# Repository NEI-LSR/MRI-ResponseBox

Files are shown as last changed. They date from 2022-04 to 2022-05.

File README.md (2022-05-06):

# MRI-ResponseBox
 Fiber optic manual response system for MRI use
 
 Contains:
  - **Code** contains the code loaded on the [Arduino](https://www.arduino.cc/en/Guide/Environment)
  - **FreeCad** contains the 3D model of the box using [FreeCad](https://www.freecadweb.org/)
  - **Eagle** contains the schematic of the electronics (see software [here](https://www.autodesk.com/products/eagle/features))

Note that the box should be put outside the scanner room (only the optic fiber should enter the room).

frontView
topView
backView

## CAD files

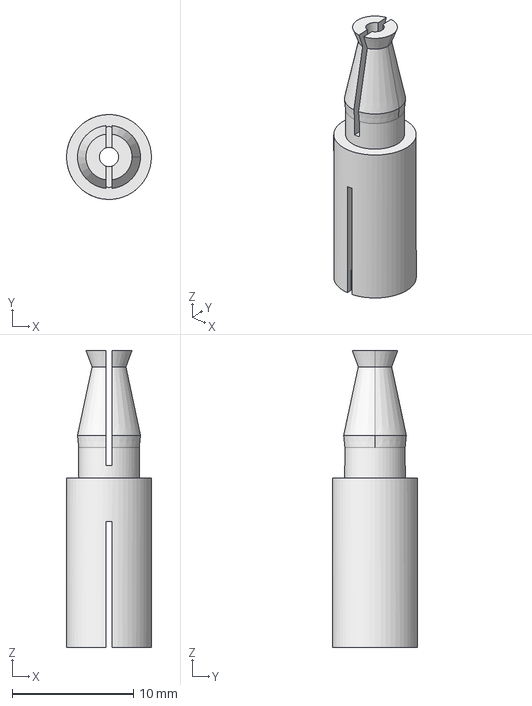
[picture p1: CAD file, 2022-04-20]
FreeCad/ResponseBoxLED-FiberConnector.FCStd
7.00 x 7.00 x 24.5 mm

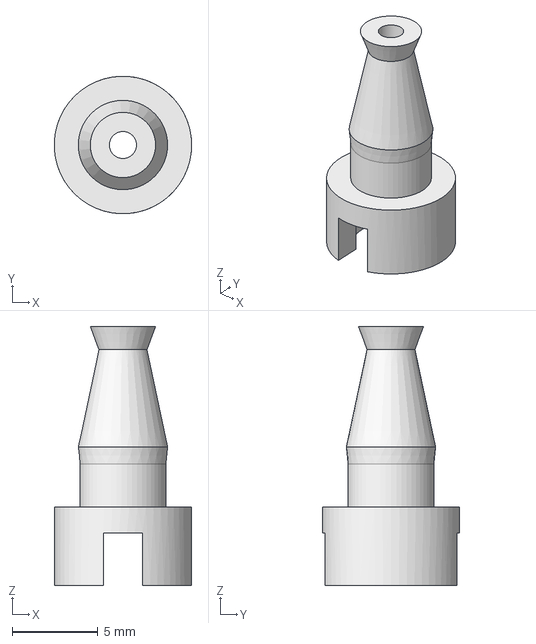
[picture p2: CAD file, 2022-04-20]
FreeCad/PhotoDiode_lgr.FCStd
7.99 x 8.00 x 15.1 mm

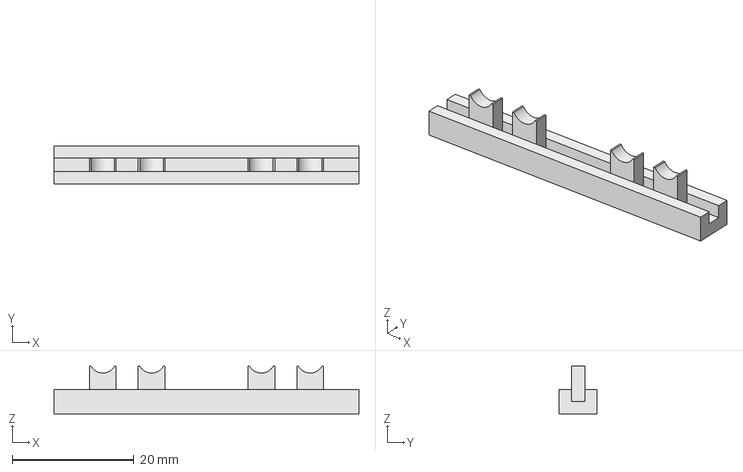
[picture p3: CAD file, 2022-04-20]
FreeCad/ResponseBox_testPlateTOP2b.FCStd
50.0 x 6.20 x 7.85 mm

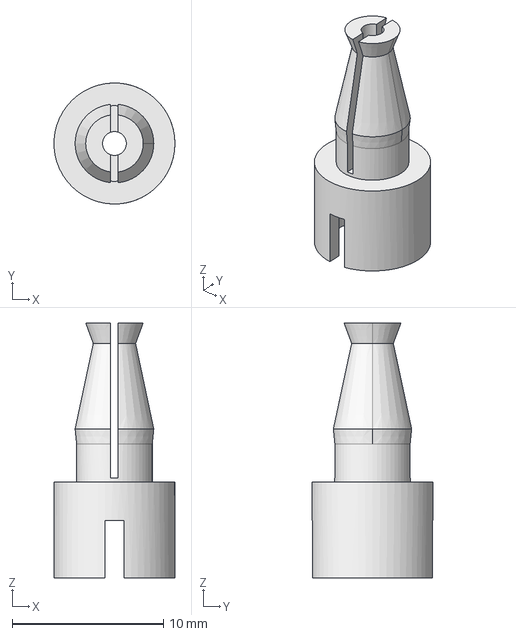
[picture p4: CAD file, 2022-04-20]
FreeCad/LaserDiode_a.FCStd
7.99 x 8.00 x 16.9 mm

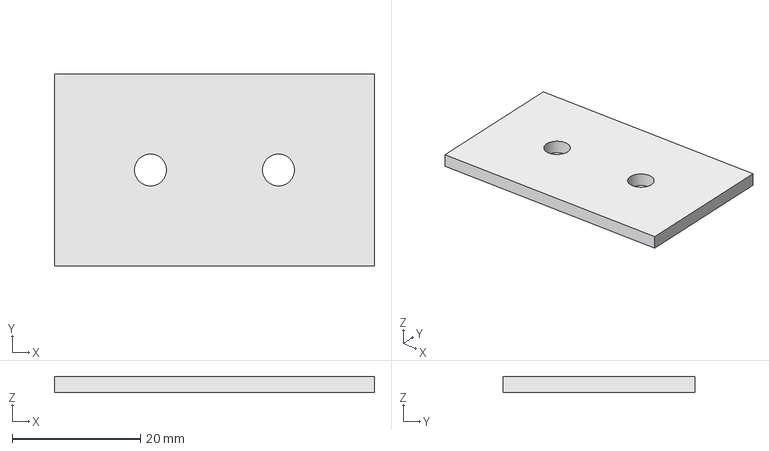
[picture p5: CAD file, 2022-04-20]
FreeCad/FiberHoldertestPlate2.FCStd
50.0 x 30.0 x 2.50 mm

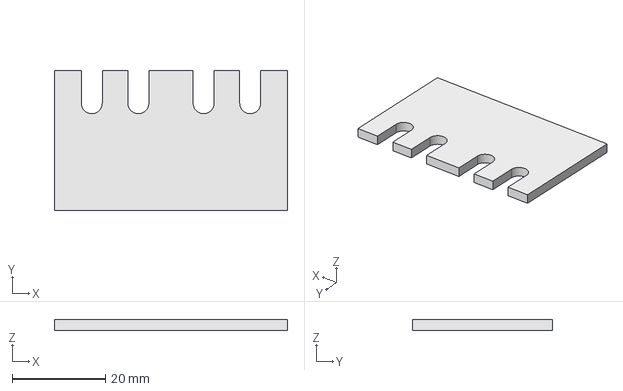
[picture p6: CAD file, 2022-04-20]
FreeCad/ResponseBox_testPlate2.FCStd
50.0 x 30.0 x 2.30 mm

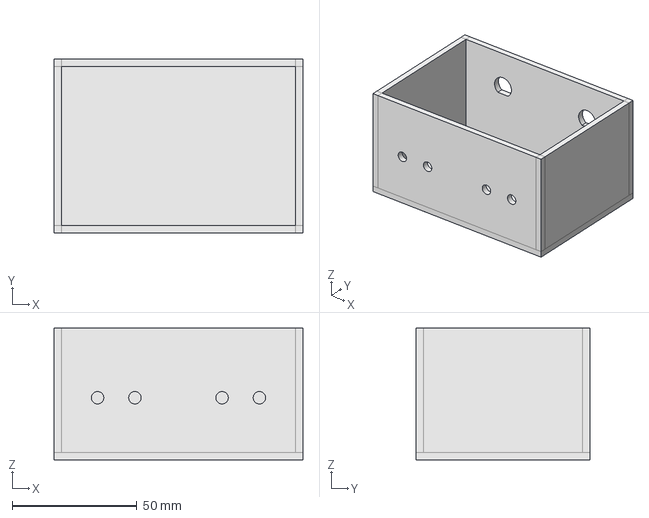
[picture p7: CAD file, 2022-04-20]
FreeCad/ResponseBox_a.FCStd
100.0 x 70.0 x 53.0 mm

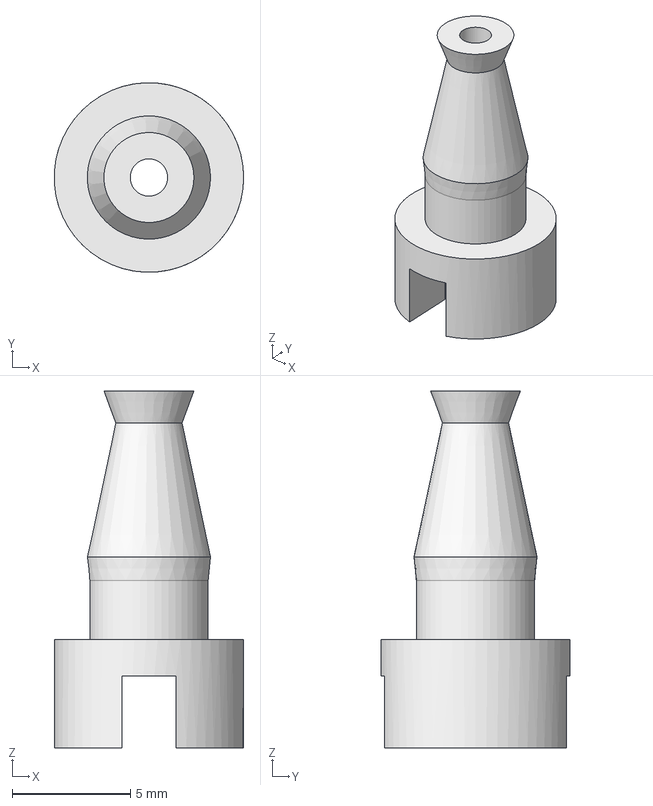
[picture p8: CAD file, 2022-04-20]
FreeCad/PhotoDiode_sm.FCStd
7.99 x 8.00 x 15.1 mm

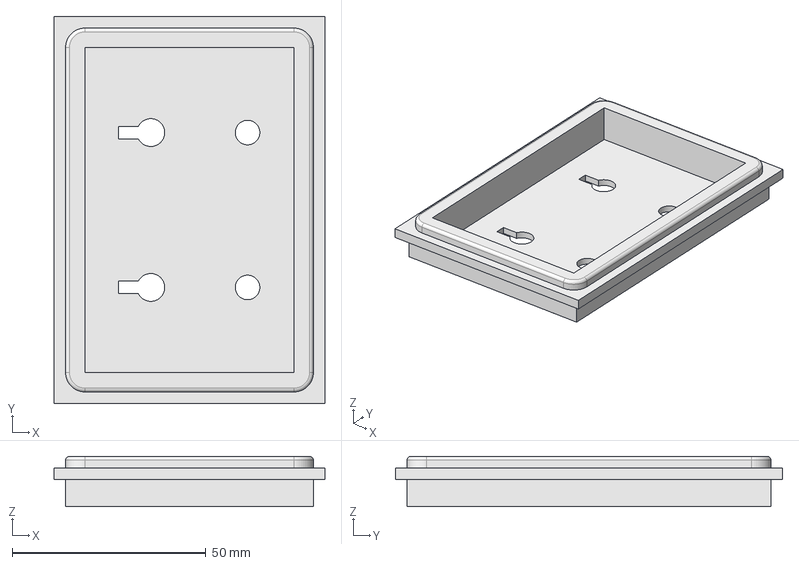
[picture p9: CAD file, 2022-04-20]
FreeCad/LickBoxTopProto2Chan.FCStd
70.0 x 100.0 x 13.0 mm

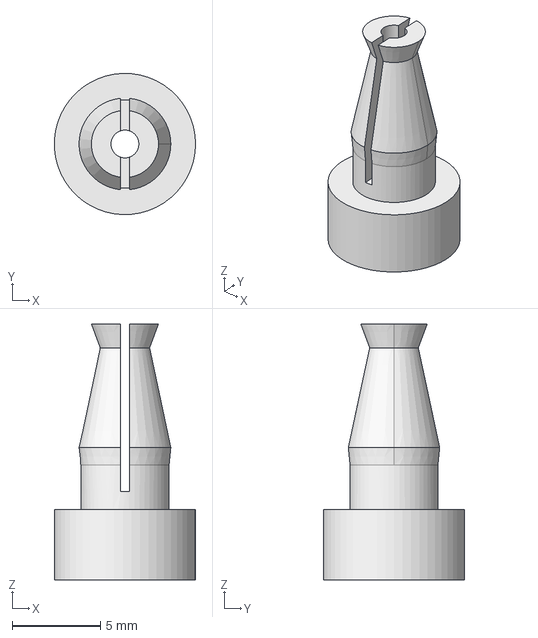
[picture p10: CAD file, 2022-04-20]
FreeCad/ResponseBoxPhotoDiode-FiberConnector.FCStd
7.99 x 8.00 x 14.5 mm

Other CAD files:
FreeCad/ResponseBox_testPlate2b.FCStd

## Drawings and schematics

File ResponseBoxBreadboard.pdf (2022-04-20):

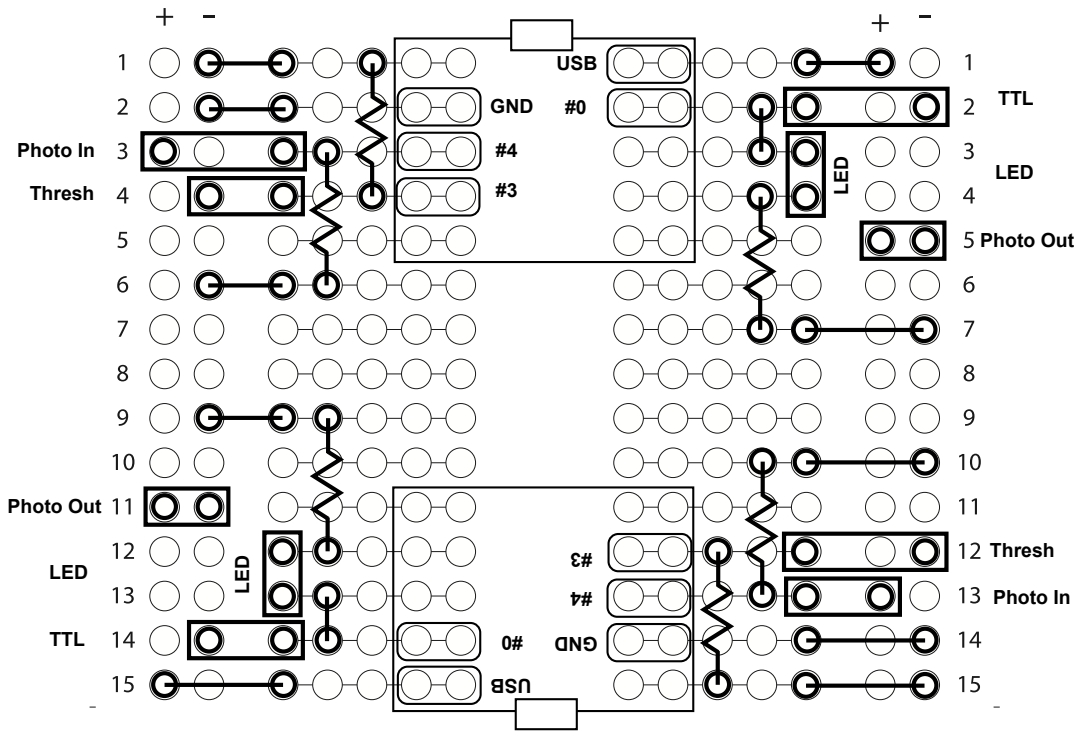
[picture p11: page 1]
USB; GND #0; Photo In; Photo Out; Thresh; TTL; LED

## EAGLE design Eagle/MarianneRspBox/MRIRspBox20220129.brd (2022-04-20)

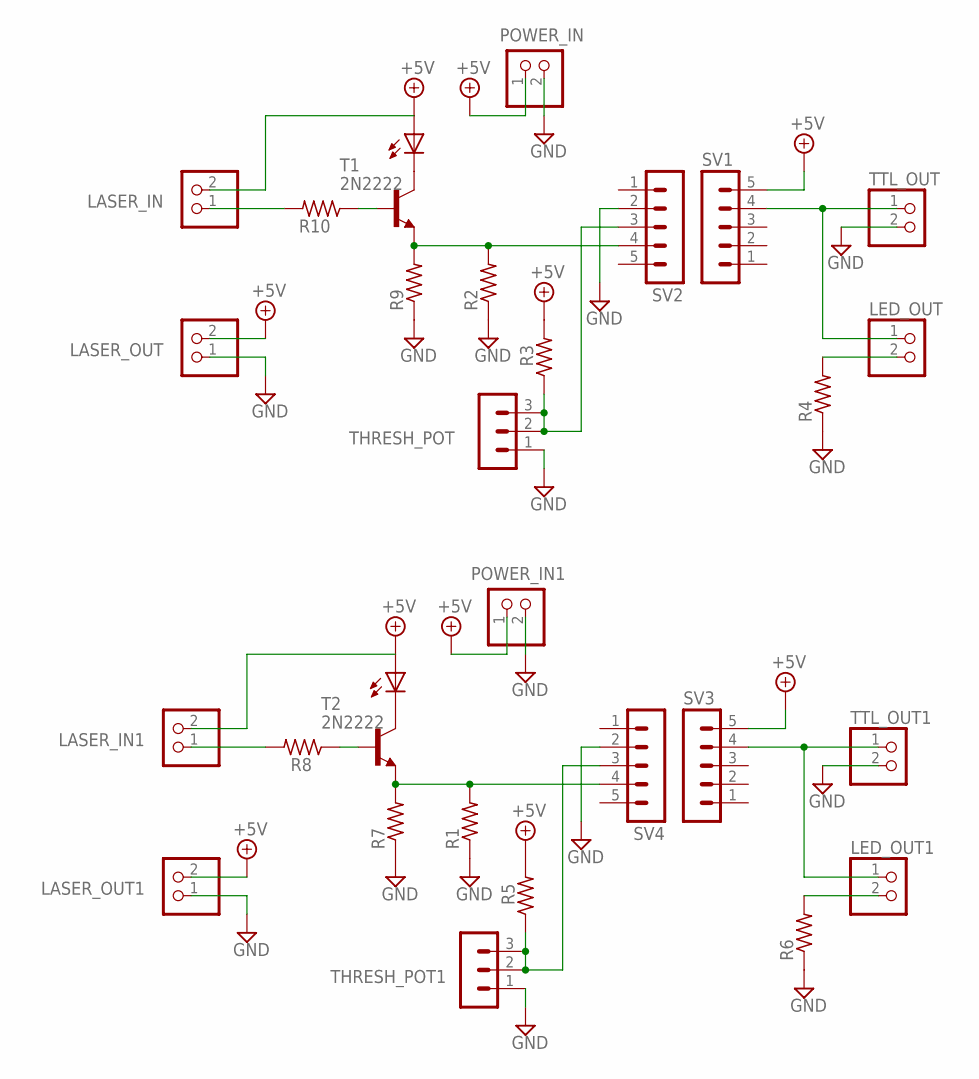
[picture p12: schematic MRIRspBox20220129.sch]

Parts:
LASER_IN, LASER_IN1: PINHD-1X2; 1X02
LASER_OUT, LASER_OUT1: PINHD-1X2; 1X02
LED1, LED2: LED_ELD260; LED_LD260
LED_OUT, LED_OUT1: PINHD-1X2; 1X02
POWER_IN, POWER_IN1: PINHD-1X2; 1X02
R1, R2, R3, R4, R5, R6, R7, R8, R9, R10: R-US_0207/12; 0207/12
SV1, SV2, SV3, SV4: MA05-1
T1, T2: 2N2222; TO92-EBC-OVAL
THRESH_POT, THRESH_POT1: MA03-1
TTL_OUT, TTL_OUT1: PINHD-1X2; 1X02

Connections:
+5V: LASER_IN.2, LASER_IN1.2, LASER_OUT.2, LASER_OUT1.2, LED1.A, LED2.A, POWER_IN.1, POWER_IN1.1, R3.2, R5.2, SV1.5, SV3.5
GND: LASER_OUT.1, LASER_OUT1.1, POWER_IN.2, POWER_IN1.2, R1.1, R2.1, R4.1, R6.1, R7.1, R9.1, SV2.2, SV4.2, THRESH_POT.1, THRESH_POT1.1, TTL_OUT.2, TTL_OUT1.2
unnamed: LED_OUT1.1, SV3.4, TTL_OUT1.1
unnamed: R5.1, SV4.3, THRESH_POT1.2, THRESH_POT1.3
unnamed: LED_OUT.1, SV1.4, TTL_OUT.1
unnamed: R3.1, SV2.3, THRESH_POT.2, THRESH_POT.3
unnamed: LED_OUT1.2, R6.2
unnamed: LASER_IN1.1, R8.2
unnamed: LED_OUT.2, R4.2
unnamed: R8.1, T2.B
unnamed: LED2.K (C), T2.C
unnamed: R1.2, R7.2, SV4.4, T2.E
unnamed: LASER_IN.1, R10.2
unnamed: R10.1, T1.B
unnamed: LED1.K (C), T1.C
unnamed: R2.2, R9.2, SV2.4, T1.E

Board: 2 copper layers, 30 parts (0 on the bottom side), 16 nets, no tracks yet.

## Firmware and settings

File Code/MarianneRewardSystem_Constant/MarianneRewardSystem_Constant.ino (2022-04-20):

// Trinket code

#define MEANHISTORY 50

// digital output states
#define PULSE_OFF 0
#define PULSE_ON 1
#define PULSE_WAIT 2

// analog input states
#define INACTIVE 0
#define ACTIVE 1

// pulse params in ms
#define ON_TIME 10
#define WAIT_TIME 90

// input magnification
//#define INPUT_SCALE 3.0
#define INPUT_SCALE 4.0

// input and output pins
int threshPin = A3;  // pin #3
int lickInput = A2;  // pin #4!
int outPin = 0;

// gather the vars for each lick channel into a structure
typedef struct lickChannel {
  int lickInput;
  int outPin;
  int threshPin;
  int inputVal = 0;
  int pulseRunning = 0;
  int pulseState = PULSE_OFF;
  long nextTransitionTime = 0;
} LickChannel;

LickChannel chan;
long channelMeanTotal;
int channelMeanCount;
int channelMean;

long threshMeanTotal;
int threshMeanCount;
int threshMean;

void setup() {

  //Serial.begin(9600);
  //  analogReference(INTERNAL);
  // assign analog input pins
  chan.lickInput = lickInput;
  pinMode(chan.lickInput, INPUT);
  chan.threshPin = threshPin;
  pinMode(chan.threshPin, INPUT);

  // assign digital output pins
  chan.outPin = outPin;
  pinMode(chan.outPin, OUTPUT);

  // initalize mean arrays
  channelMeanTotal = 0;
  channelMeanCount = 0;
  channelMean = 0;
  threshMeanTotal = 0;
  threshMeanCount = 0;
  threshMean = 0;
}

void loop() {

  // check for analog input over threshold
  if (inputAboveThreshold()) {
    chan.inputVal = ACTIVE;
    chan.pulseState = PULSE_ON;
  } else {
    chan.inputVal = INACTIVE;
    chan.pulseState = PULSE_OFF;
  }

  // tend to the TTL output pulses
  setPulseValue();
}


//////////////////////////////////////////////
int inputAboveThreshold() {
  // read the pins
  int inputVal = analogRead(chan.lickInput);
  inputVal = analogRead(chan.lickInput);
  inputVal = (int)((double)inputVal * INPUT_SCALE);

  int threshVal = analogRead(chan.threshPin);
  threshVal = analogRead(chan.threshPin);


  return (inputVal > threshVal);

  int mean = updateMean(inputVal);
  inputVal = inputVal - mean;
  inputVal = inputVal < 0 ? 0 : inputVal;


  int thresh = updateThresh(threshVal);
  thresh = threshVal - threshMean;
  thresh = thresh < 0 ? 0 : thresh;

  // subtract off the mean from the input and scale it
  inputVal = (int)((double)inputVal * INPUT_SCALE);

  return (inputVal > thresh);
}

//////////////////////////////////////////////
int setPulseValue() {
  if (chan.inputVal == ACTIVE) {
    digitalWrite(chan.outPin, HIGH);
  } else {
    digitalWrite(chan.outPin, LOW);
  }
}

//////////////////////////////////////////////
int updateMean(int value) {
  if (channelMeanCount + 1 >= MEANHISTORY) {
    int newCount = MEANHISTORY / 2;
    int newTotal = channelMeanTotal / 2;
    channelMeanCount = newCount;
    channelMeanTotal = newTotal;
  }

  channelMeanCount++;
  channelMeanTotal += value;

  channelMean = channelMeanTotal / channelMeanCount;

  return channelMean;
}

//////////////////////////////////////////////
int updateThresh(int value) {

  if (chan.inputVal == INACTIVE) {
    if (threshMeanCount + 1 >= MEANHISTORY) {
      int newCount = MEANHISTORY / 2;
      int newTotal = threshMeanTotal / 2;
      threshMeanCount = newCount;
      threshMeanTotal = newTotal;
    }

    threshMeanCount++;
    threshMeanTotal += value;
  }
  threshMean = threshMeanTotal / threshMeanCount;

  return threshMean;
}
